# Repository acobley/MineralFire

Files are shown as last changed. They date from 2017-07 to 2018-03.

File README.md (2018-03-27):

View this project on [CADLAB.io](https://cadlab.io/node/793). 

# Volca_Pulse

Software for MineralFire Eurorack module.

This is an Arduino based programmable clock divider.  

NOTES
The Most up to date branch is "AltCounter"

The hardware design is in testing, do not use for production. 

The Software works, but is still under development.

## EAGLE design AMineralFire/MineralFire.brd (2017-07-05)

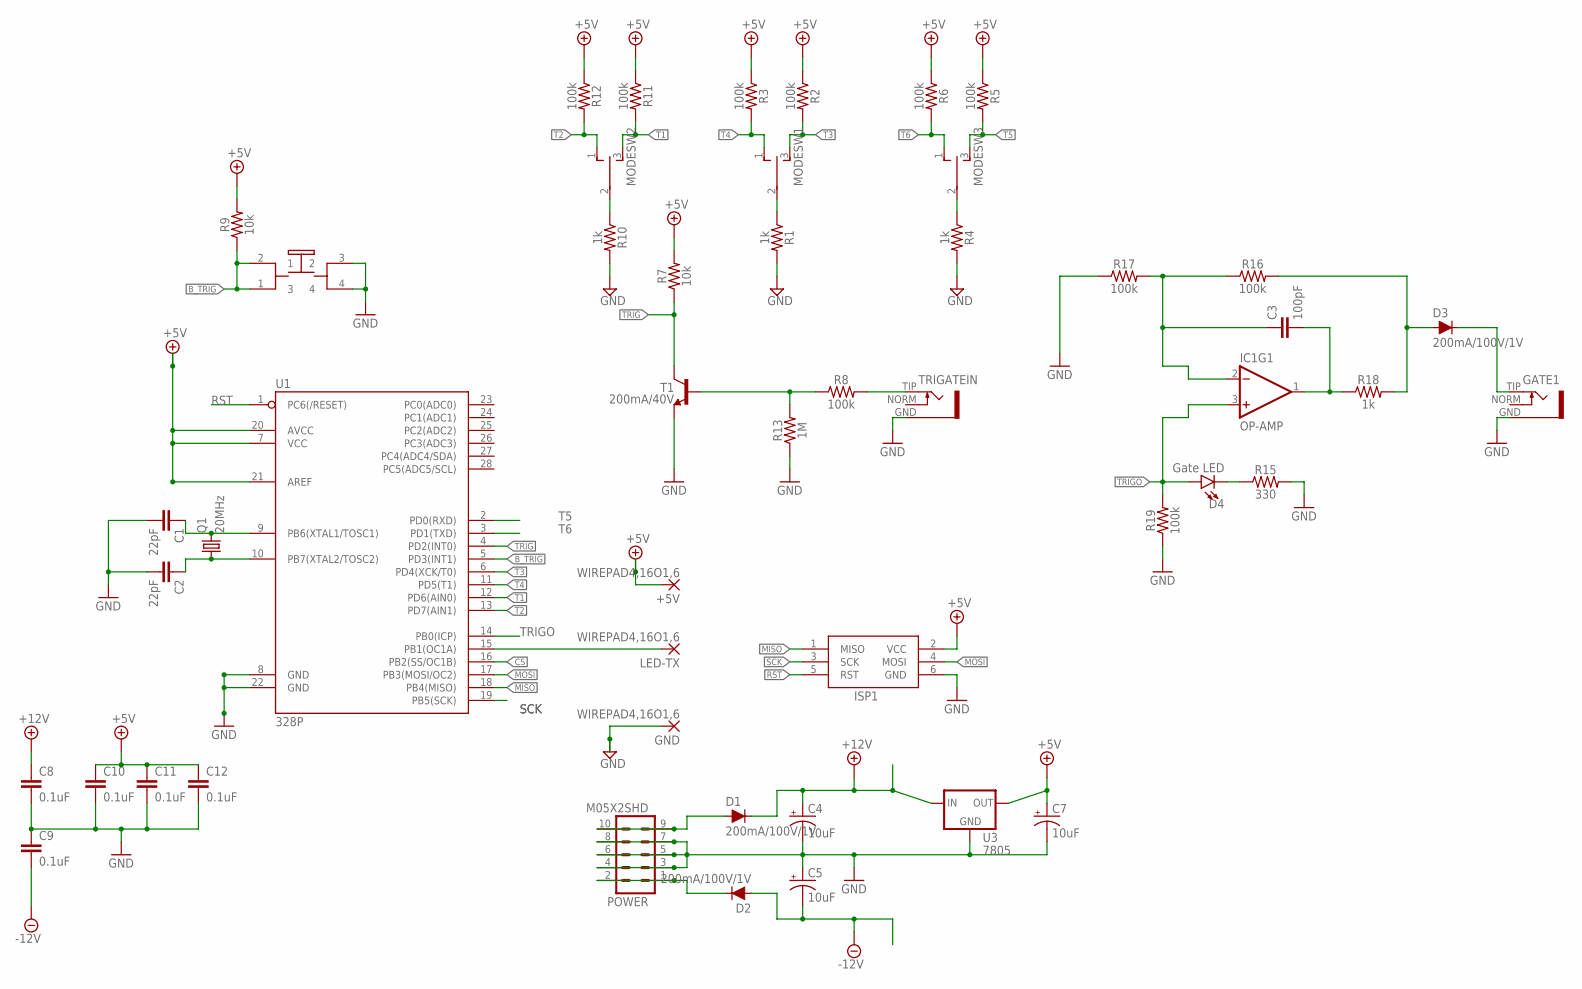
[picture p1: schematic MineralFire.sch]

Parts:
+5V: WIREPAD4,16O1,6; 4,16O1,6
C1, C2: 22pF; CAP-PTH-2.54
C3: 100pF; 0603
C4, C5, C7: 10uF; CPOL-RADIAL-2.5MM-5MM
C8, C9, C10, C11, C12: 0.1uF; CAP-PTH-SMALL-KIT
D1, D2, D3: 200mA/100V/1V; DIODE-1N4148
D4: Gate LED; LED_3MM
GATE1: S_JACK
GND: WIREPAD4,16O1,6; 4,16O1,6
IC1: OP-AMP; SO08
ISP1: AVRISP-6; AVRISP
LED-TX: WIREPAD4,16O1,6; 4,16O1,6
MODESW1, MODESW2, MODESW3: TOGGLE_ON_OFF_ON
POWER: M05X2SHD; 2X5-SHROUDED
Q1: 20MHz; HC49UP
R1, R4, R10, R18: 1k; AXIAL-0.3
R2, R3, R5, R6, R8, R11, R12, R16, R17, R19: 100k; AXIAL-0.3
R7, R9: 10k; AXIAL-0.3
R13: 1M; AXIAL-0.3
R15: 330; AXIAL-0.3
START: PB6149L-5; PB6149L
T1: 200mA/40V; TO-92
TRIGATEIN: S_JACK
U1: 328P; DIP28
U3: 7805; DC-DC_CONVERTER_78XX

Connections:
+5V: +5V.1, C7.1 (+), C10.1, C11.1, C12.1, ISP1.2 (VCC), R2.P$1 (1), R3.P$1 (1), R5.P$1 (1), R6.P$1 (1), R7.P$2 (2), R9.P$2 (2), R11.P$1 (1), R12.P$1 (1), U1.7 (VCC), U1.20 (AVCC), U1.21 (AREF), U3.VOUT (OUT)
+12V: C4.1 (+), C8.1, D1.C, U3.VIN (IN)
-12V: C5.2 (-), C9.2, D2.A
B_TRIG: R9.P$1 (1), START.1 (3), START.2 (1), U1.5 (PD3(INT1))
CS: U1.16 (PB2(SS/OC1B))
GND: C1.2, C2.2, C4.2 (-), C5.1 (+), C7.2 (-), C8.2, C9.1, C10.2, C11.2, C12.2, GATE1.GND, GND.1, ISP1.6 (GND), POWER.3, POWER.4, POWER.5, POWER.6, POWER.7, POWER.8, R1.P$2 (2), R4.P$2 (2), R10.P$2 (2), R13.P$1 (1), R15.P$2 (2), R17.P$1 (1), R19.P$1 (1), START.3 (2), START.4, T1.1 (E), TRIGATEIN.GND, U1.8 (GND), U1.22 (GND), U3.GND
MISO: ISP1.1 (MISO), U1.18 (PB4(MISO))
MOSI: ISP1.4 (MOSI), U1.17 (PB3(MOSI/OC2))
unnamed: C1.1, Q1.2, U1.9 (PB6(XTAL1/TOSC1))
unnamed: C2.1, Q1.1, U1.10 (PB7(XTAL2/TOSC2))
unnamed: MODESW1.2, R1.P$1 (1)
unnamed: MODESW3.2, R4.P$1 (1)
unnamed: LED-TX.1, U1.15 (PB1(OC1A))
unnamed: D1.A, POWER.9, POWER.10
unnamed: D2.C, POWER.1, POWER.2
unnamed: MODESW2.2, R10.P$1 (1)
unnamed: R8.P$1 (1), R13.P$2 (2), T1.2 (B)
unnamed: R8.P$2 (2), TRIGATEIN.TIP
unnamed: D4.K (C), R15.P$1 (1)
unnamed: C3.1, IC1.2 (-IN), R16.P$1 (1), R17.P$2 (2)
unnamed: C3.2, IC1.1 (OUT), R18.P$1 (1)
unnamed: D3.A, R16.P$2 (2), R18.P$2 (2)
unnamed: D3.C, GATE1.TIP
RST: ISP1.5 (RST), U1.1 (PC6(/RESET))
SCK: ISP1.3 (SCK), U1.19 (PB5(SCK))
T1: MODESW2.3 (S), R11.P$2 (2), U1.12 (PD6(AIN0))
T2: MODESW2.1 (O), R12.P$2 (2), U1.13 (PD7(AIN1))
T3: MODESW1.3 (S), R2.P$2 (2), U1.6 (PD4(XCK/T0))
T4: MODESW1.1 (O), R3.P$2 (2), U1.11 (PD5(T1))
T5: MODESW3.3 (S), R5.P$2 (2), U1.2 (PD0(RXD))
T6: MODESW3.1 (O), R6.P$2 (2), U1.3 (PD1(TXD))
TRIG: R7.P$1 (1), T1.3 (C), U1.4 (PD2(INT0))
TRIGO: D4.A, IC1.3 (+IN), R19.P$2 (2), U1.14 (PB0(ICP))

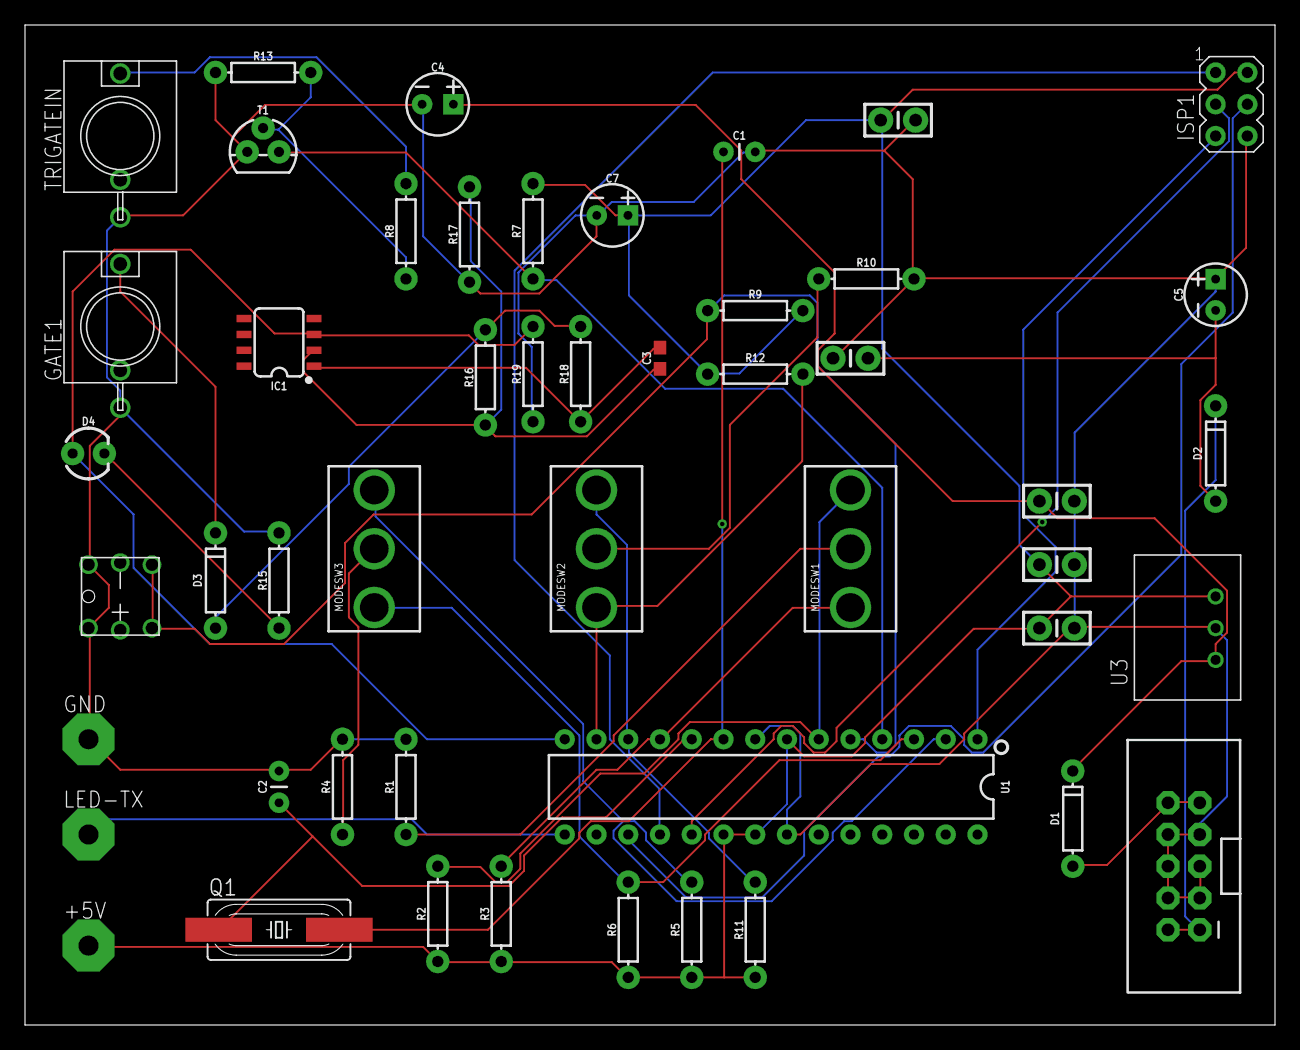
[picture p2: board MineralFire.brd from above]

Board: 2 copper layers, 100.0 x 80.0 mm, 49 parts (0 on the bottom side), 32 nets.

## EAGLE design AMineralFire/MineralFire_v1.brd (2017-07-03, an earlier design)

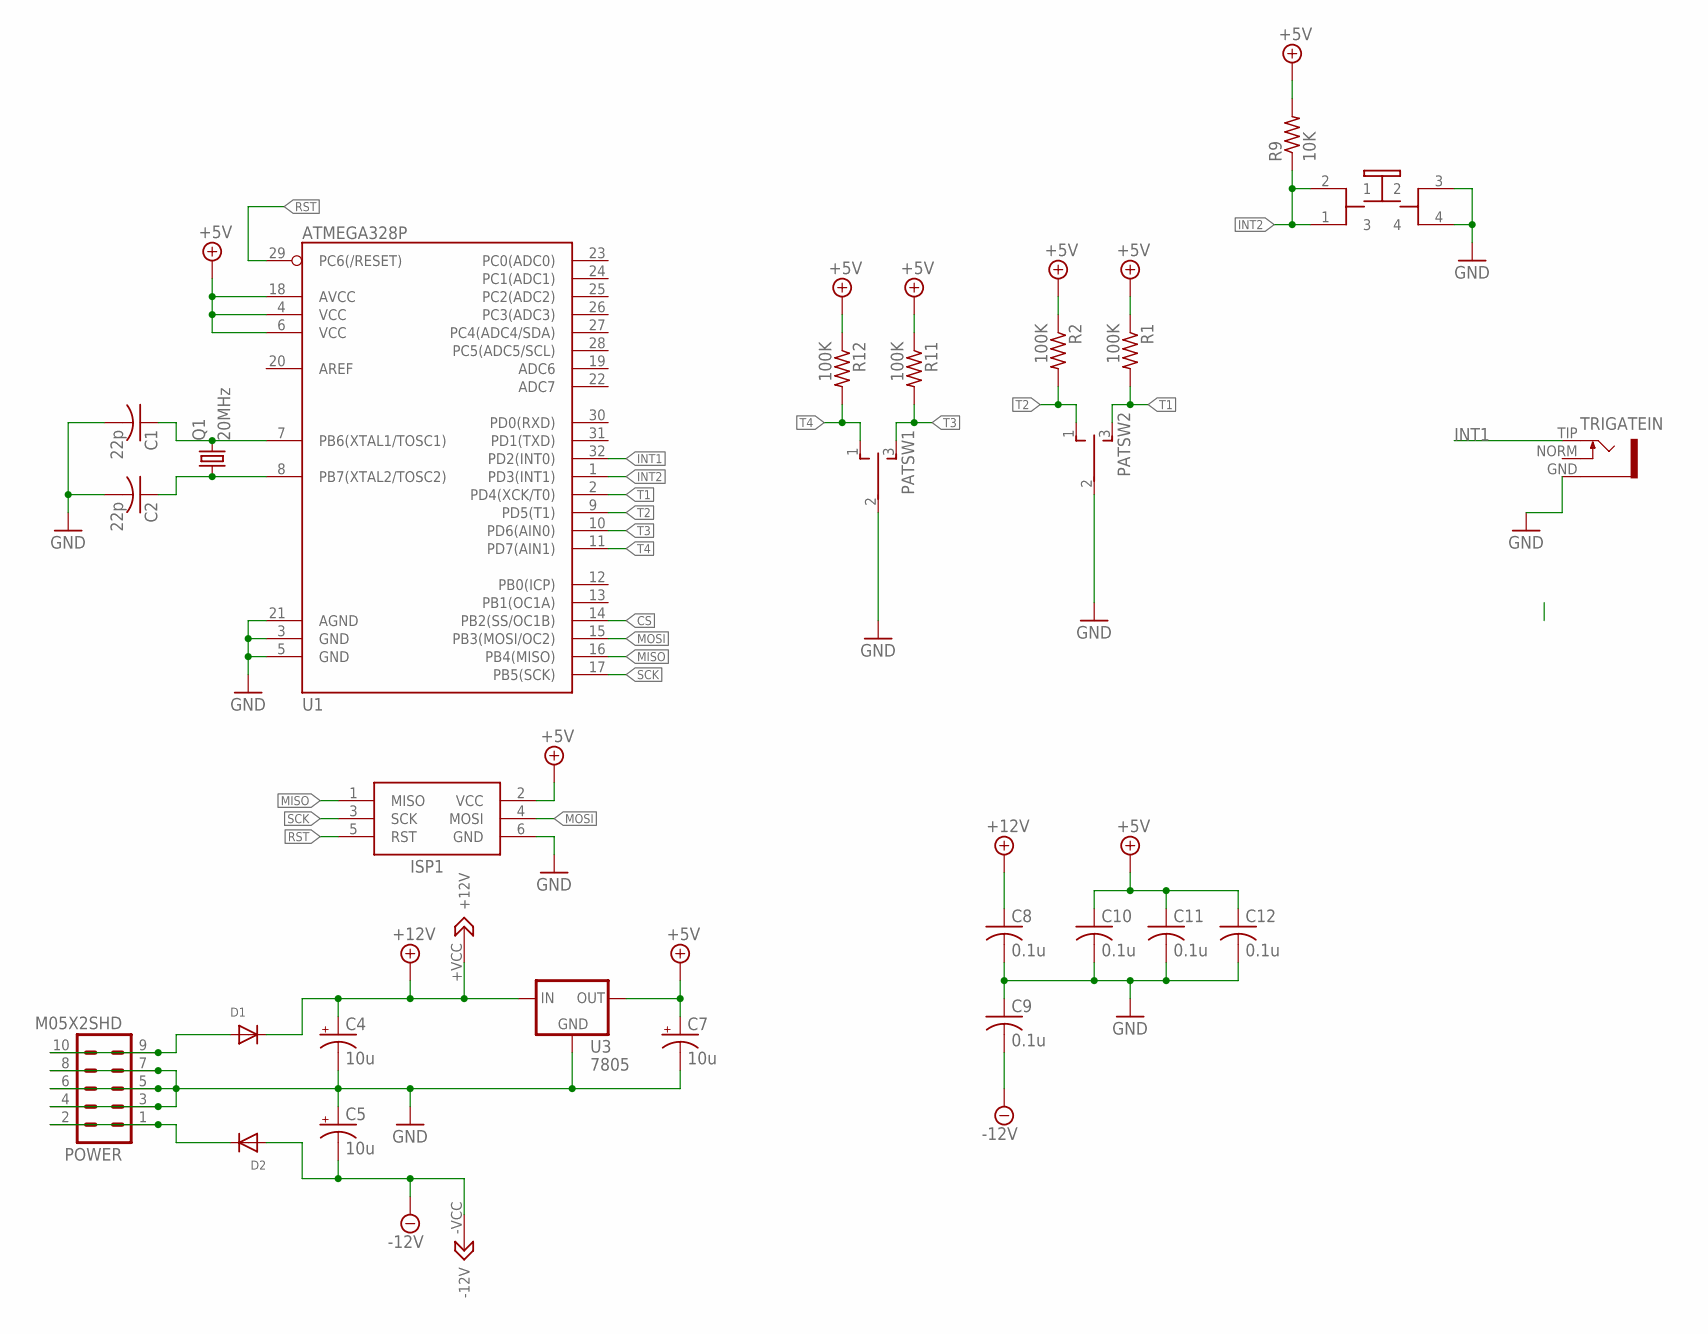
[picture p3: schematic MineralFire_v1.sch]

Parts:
BUT: PB6149L-5; PB6149L
C1, C2: 22p; C0805K
C4, C5, C7: 10u; 153CLV-0505
C8, C9, C10, C11, C12: 0.1u; C0805K
D1, D2: DIODESMA; SMADIODE
ISP1: AVRISP-6; AVRISP
PATSW1, PATSW2: TOGGLE_ON_OFF_ON
POWER: M05X2SHD; 2X5-SHROUDED
Q1: 20MHz; HC49UP
R1, R2, R11, R12: 100K; R0805
R9: 10K; R0805
TRIGATEIN: S_JACK
U1: ATMEGA328P; TQFP32-08
U2: DUAL_OPAMP
U3: 7805; V-REG

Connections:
+5V: C7.+, C10.1, C11.1, C12.1, ISP1.2 (VCC), R1.1, R2.1, R9.2, R11.1, R12.1, U1.4 (VCC), U1.6 (VCC), U1.18 (AVCC), U3.3 (OUT)
+12V: C4.+, C8.1, D1.C, U2.+VCC (+12V), U3.1 (IN)
-12V: C5.-, C9.2, D2.A, U2.-VCC (-12V)
CS: U1.14 (PB2(SS/OC1B))
GND: BUT.3 (2), BUT.4, C1.2, C2.2, C4.-, C5.+, C7.-, C8.2, C9.1, C10.2, C11.2, C12.2, ISP1.6 (GND), PATSW1.2, PATSW2.2, POWER.3, POWER.4, POWER.5, POWER.6, POWER.7, POWER.8, TRIGATEIN.GND, U1.3 (GND), U1.5 (GND), U1.21 (AGND), U3.4 (GND)
INT1: TRIGATEIN.TIP, U1.32 (PD2(INT0))
INT2: BUT.1 (3), BUT.2 (1), R9.1, U1.1 (PD3(INT1))
MISO: ISP1.1 (MISO), U1.16 (PB4(MISO))
MOSI: ISP1.4 (MOSI), U1.15 (PB3(MOSI/OC2))
unnamed: C1.1, Q1.2, U1.7 (PB6(XTAL1/TOSC1))
unnamed: C2.1, Q1.1, U1.8 (PB7(XTAL2/TOSC2))
unnamed: D1.A, POWER.9, POWER.10
unnamed: D2.C, POWER.1, POWER.2
RST: ISP1.5 (RST), U1.29 (PC6(/RESET))
SCK: ISP1.3 (SCK), U1.17 (PB5(SCK))
T1: PATSW2.3 (S), R1.2, U1.2 (PD4(XCK/T0))
T2: PATSW2.1 (O), R2.2, U1.9 (PD5(T1))
T3: PATSW1.3 (S), R11.2, U1.10 (PD6(AIN0))
T4: PATSW1.1 (O), R12.2, U1.11 (PD7(AIN1))

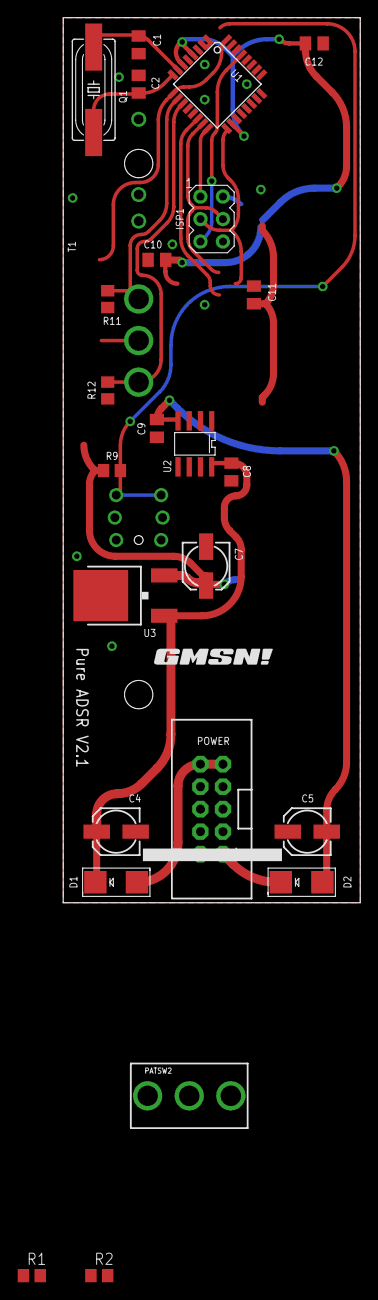
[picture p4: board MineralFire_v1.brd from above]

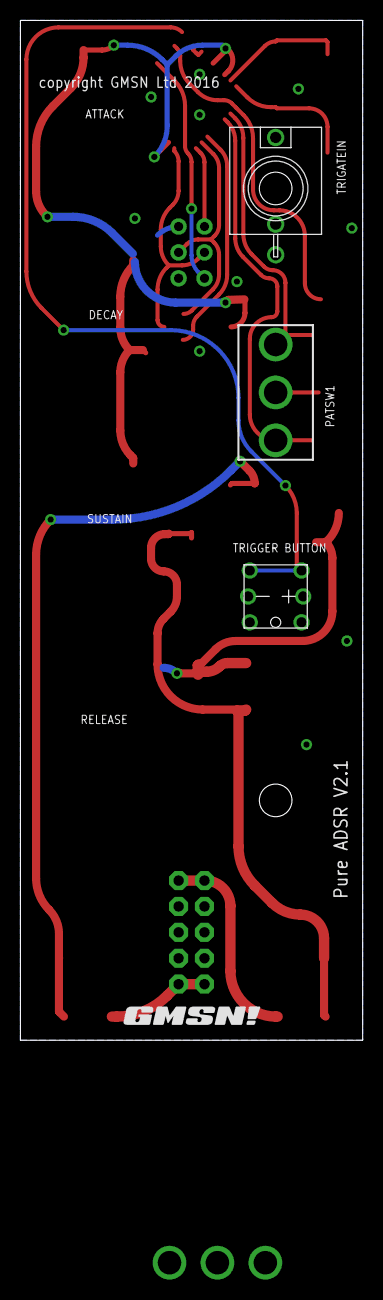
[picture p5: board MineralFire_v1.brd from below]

Board: 2 copper layers, 33.6 x 100.0 mm, 29 parts (4 on the bottom side), 18 nets.

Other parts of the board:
U$1, U$2: GMSN!_LOGO

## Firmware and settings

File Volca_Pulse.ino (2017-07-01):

#include <SoftwareSerial.h>

volatile byte DivPulseCounter = 0;
volatile byte NumPulseCounter = 0;
boolean state[] = {false, false, false, false};
volatile boolean running = false;
int pins[] = {13, 12, 11, 10};
byte SwitchConvert[]={1,3,2}; //We use this to convert from the numbers the switch puts out to a sensible 


int DivFactors[3][4] = {{4, 4, 2, 1},
                        {4,2,4,2},
                        {3,5,3,7}};
int NumberPulses[3][4] = {{8, 8, 4, 8},
                          {8,4,8,4},
                          {9,10,9,14}};

byte DivSwitch=0; //Used to set the pattern by the switches
byte PulseSwitch=0;

volatile byte CurrentPtr = 0; //how far through the current Bars we are

byte CurrentDivFactor = DivFactors[DivSwitch][CurrentPtr];
byte CurrentPulseLength = NumberPulses[PulseSwitch][CurrentPtr];


const byte interruptPin = 2;
const byte switchinterruptPin = 3;
const int Switch = 9; // We need this connection because we can't read the interrupt pin (I think!)
const int SW11=4; //These define the two switches for selecting patterns
const int SW12=5;
const int SW21=7;
const int SW22=6;

SoftwareSerial Serial7Segment(7, 8); //RX pin, TX pin
char tempString[10]; //Used for sprintf

// the setup function runs once when you press reset or power the board
void setup() {
  // initialize digital pin 13 as an output.
  pinMode(13, OUTPUT);
  pinMode(12, OUTPUT);
  pinMode(11, OUTPUT);
  pinMode(10, OUTPUT);
  pinMode(Switch, INPUT);
  pinMode(SW11,INPUT);
  pinMode(SW12,INPUT);
  pinMode(SW21,INPUT);
  pinMode(SW22,INPUT);
  pinMode(LED_BUILTIN, OUTPUT);
  attachInterrupt(digitalPinToInterrupt(interruptPin), HandleClock, RISING);
  attachInterrupt(digitalPinToInterrupt(switchinterruptPin), Run, RISING); // Note only one interrupt can be attached to an input
  Serial.begin(9600);
  Serial7Segment.begin(9600); //Talk to the Serial7Segment at 9600 bps
  Serial7Segment.write('v'); //Reset the display - this forces the cursor to return to the beginning of the display

}

void Run() {
  DivPulseCounter = 0;
  NumPulseCounter = 0;
  running = true;
  Serial7Segment.print("RRRR"); //Send serial string out the soft serial port to the S7S

}

void Stop() {
  running = false;
  //Serial7Segment.print("5555"); //Send serial string out the soft serial port to the S7S
}

void SetPin(int pin, boolean state) {
  digitalWrite(pins[pin], state);

}


void DisplayNumbers(byte A,byte B, byte C, byte  D){
  char c4=' ';
  char c3=' ';
  char c2=' ';
  char c1=' ';
  if (A<100) //NUmbers greater than 100 are blank for convienience
     c4='0'+A;
   if (B<100)
     c3='0'+B;
  if (C<100)
     c2='0'+C;
  if (D<100)
     c1='0'+D;        

  tempString[0]=c4;
  tempString[1]=c3;
  tempString[2]=c2;
  tempString[3]=c1;
  tempString[4]='\0';
  Serial7Segment.print(tempString);  
//  Serial.println(tempString);
}


void ReadPatternSwitches(){
   byte cSW11=1;
   byte cSW12=1;
   byte cSW21=1;
   byte cSW22=1;
    if (digitalRead(SW11) == LOW) {
       cSW11=0;   
  }
  if (digitalRead(SW12) == LOW) {
       cSW12=0;   
  }

  if (digitalRead(SW21) == LOW) {
       cSW21=0;   
  }
  if (digitalRead(SW22) == LOW) {
       cSW22=0;   
  }  
  byte SW1=2*cSW12+cSW11;
  SW1=SwitchConvert[SW1-1];


  byte SW2=2*cSW21+cSW22;
  SW2=SwitchConvert[SW2-1];
  DivSwitch=SW1-1;
  PulseSwitch=SW2-1;
  
  int tmp=SW1+100*SW2;
  if (running ==false){
     DisplayNumbers(110,SW2,110,SW1);
  }
}

void HandleClock() {
  Serial7Segment.write('v'); //Reset the display - this forces the cursor to return to the beginning of the display
  ReadPatternSwitches();
  if (digitalRead(Switch) == LOW) {
    Stop();
  }
  if (running == true) {

    DisplayNumbers(CurrentPtr,CurrentPulseLength,CurrentDivFactor,DivPulseCounter);
    if (DivPulseCounter < CurrentDivFactor) {


      DivPulseCounter++;
      if (DivPulseCounter >= CurrentDivFactor) {
        Pulse();
        DivPulseCounter = 0;
      }
    }
    if (NumPulseCounter < CurrentPulseLength) {
      NumPulseCounter++;
      if (NumPulseCounter >= CurrentPulseLength) {
        NumPulseCounter = 0;
        CurrentPtr++;
        if (CurrentPtr < 4) {
          CurrentDivFactor = DivFactors[DivSwitch][CurrentPtr];
          CurrentPulseLength = NumberPulses[PulseSwitch][CurrentPtr];
        } else {
          CurrentPtr = 0;
          CurrentDivFactor = DivFactors[DivSwitch][CurrentPtr];
          CurrentPulseLength = NumberPulses[PulseSwitch][CurrentPtr];
        }

      }
    }
  }
}


void Pulse() {


  int i = 0;
  SetPin(0, HIGH);
  for (i = 0; i < 1000; i++) {
    int j = i * 10; //Add some delay work
  }

  SetPin(0, LOW);

}
// the loop function runs over and over again forever
void loop() {
 



}

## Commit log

2017-02-08 built in led flash
2017-02-19 LED support
2017-02-25 dimed LEd, fixed count issue
    [Volca_Pulse.ino]
2017-03-05 added running switch
2017-07-01 New Switches for patterns
2017-07-03 added Eagle files
    [MineralFire_v1.brd, MineralFire_v1.sch]
2017-07-05 Working on moving SMT to tru-the hole
    [MineralFire.brd, MineralFire.sch]
2017-07-05 First Attempt at layout
    [MineralFire.brd, MineralFire.sch]

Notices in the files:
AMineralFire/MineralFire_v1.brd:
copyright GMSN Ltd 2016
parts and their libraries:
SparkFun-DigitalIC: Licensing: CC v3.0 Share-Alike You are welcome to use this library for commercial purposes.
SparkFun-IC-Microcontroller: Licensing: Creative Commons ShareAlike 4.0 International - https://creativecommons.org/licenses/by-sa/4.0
